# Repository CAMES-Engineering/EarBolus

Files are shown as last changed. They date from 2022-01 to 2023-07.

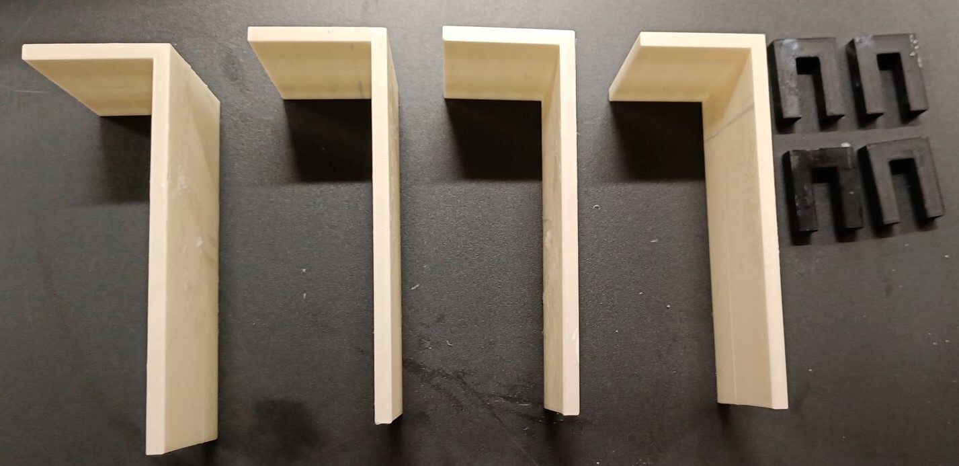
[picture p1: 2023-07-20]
ideas/mouldbox.jpg

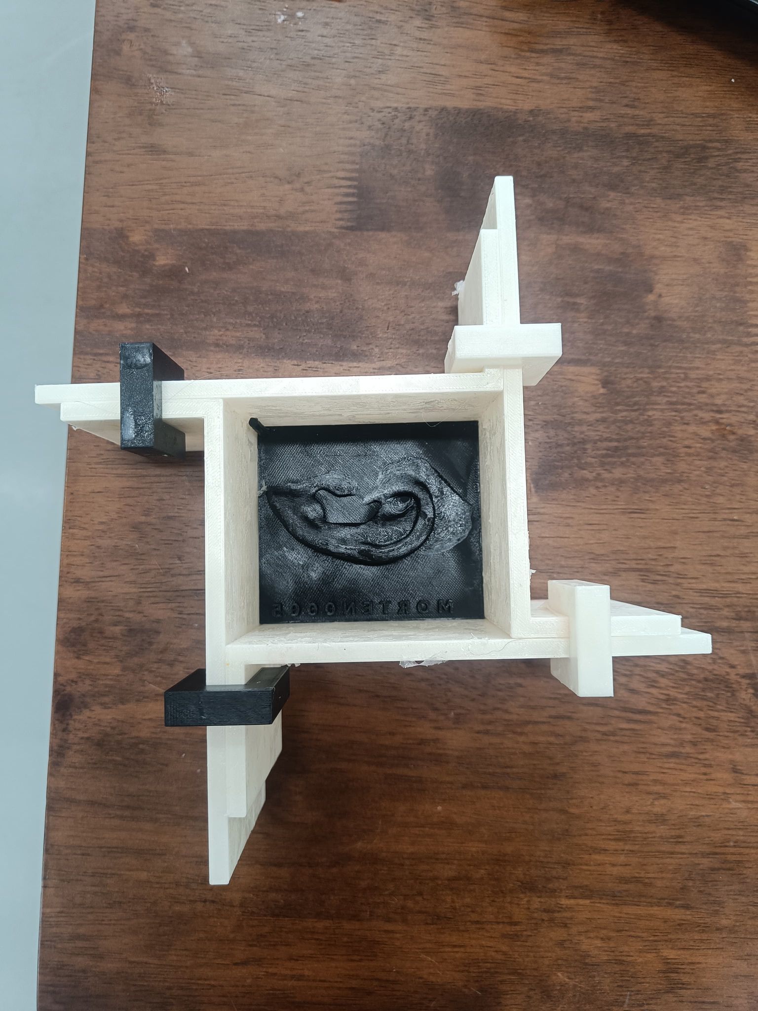
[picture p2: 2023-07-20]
ideas/311189066_1258065511643426_81849883111388684_n (1) (1).jpg

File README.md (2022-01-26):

# EarBolus

# Projekt trin

Aftalte trin med Kiki  
 + Text i model

Lav trin i denne fil.

Overvej om der skal laves ændringerne i ørefilerne for at de kan printes.

Meshmixer til smoothing af øre

# Færdige trin

<del>Kiki status</del>

---

## Requirements

Krav til Bolus i silikone
10mm over højeste sted på øret

### Spørgsmål
Hvad er præcisionskravet ?

### First attempts

1 - Kasse (Generisk)  
2 - Øre der passer i
    Skæres flad i bunden så den kan lægge i formen
3 - Målestok til at hælde silikone i

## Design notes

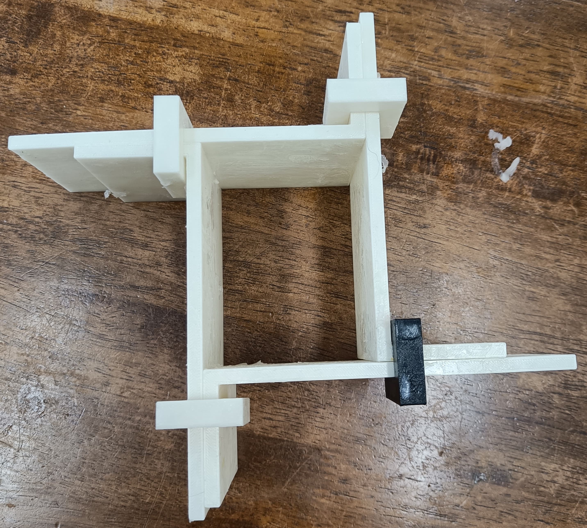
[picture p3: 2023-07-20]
ideas/mouldboxcollected.jpg

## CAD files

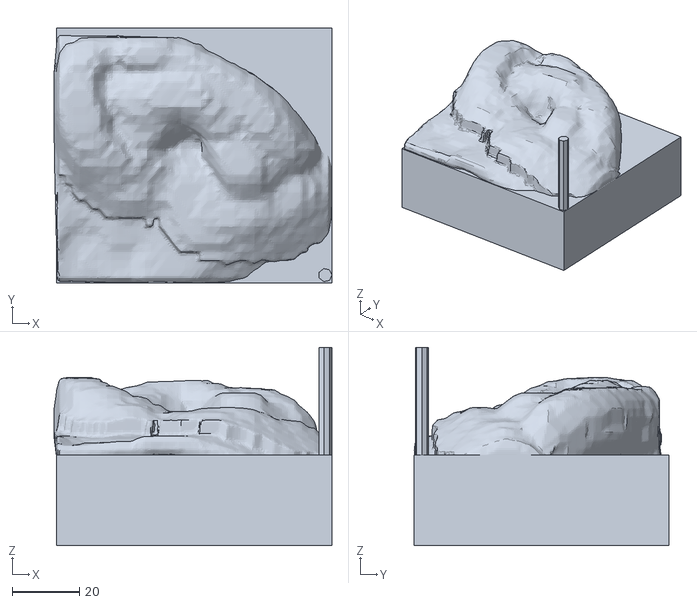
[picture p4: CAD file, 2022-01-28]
ideas/earcylinder.stl
82.7 x 76.0 x 59.0

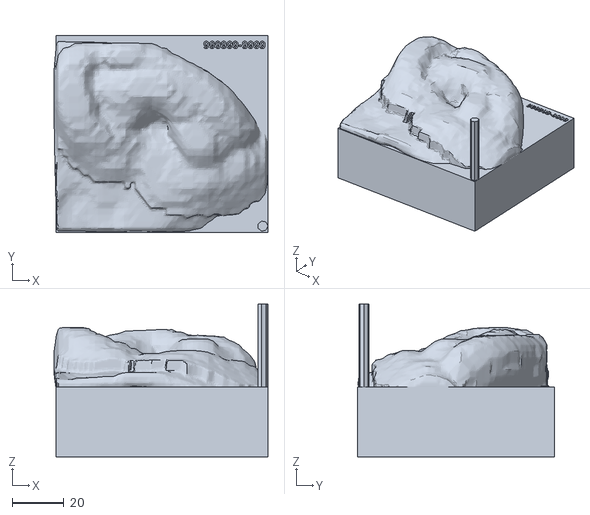
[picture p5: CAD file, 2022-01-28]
ideas/w_CPRearcylinder.stl
82.7 x 76.0 x 59.0

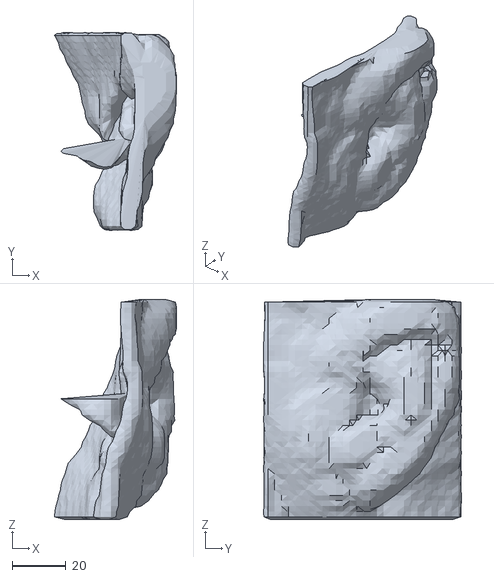
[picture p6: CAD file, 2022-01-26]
ideas/Bolus.stl
45.5 x 73.9 x 82.0

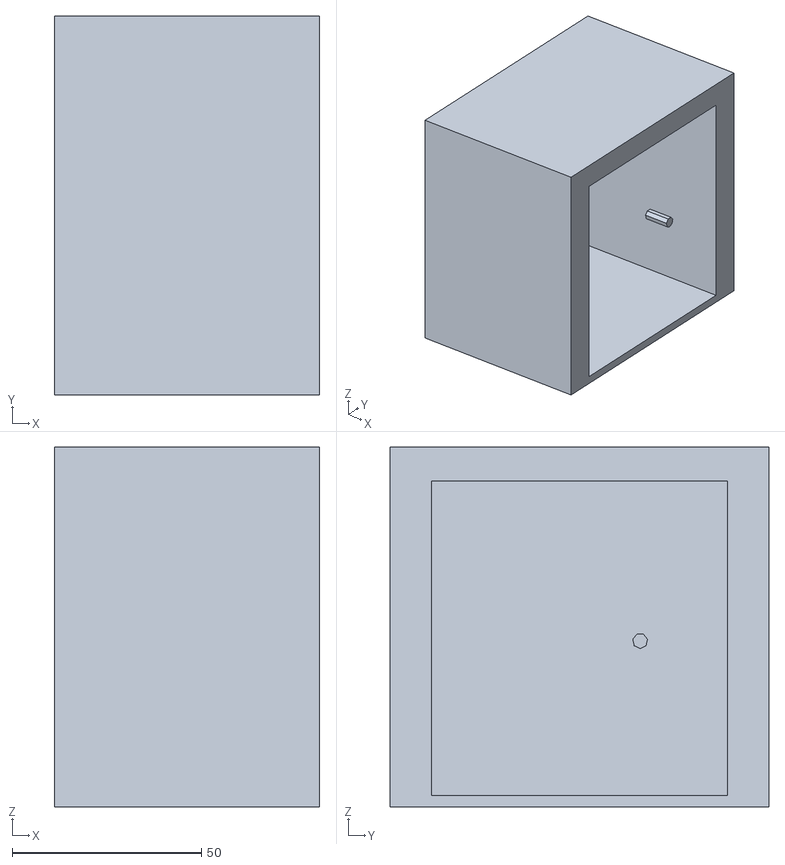
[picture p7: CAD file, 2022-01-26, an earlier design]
ideas/old/kassebolusmeassurerigtige.stl
70.0 x 100.0 x 95.0

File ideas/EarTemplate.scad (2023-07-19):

include <includingScriptEarBolus.scad>
// IMPORTANT make sure the EarTemplate.scad and includingScriptEarBolus.scad are located in the same folder

// Insert the file path here. You can drag and drop it, or copy the file path. If you drag and drop remember to remove <import()>
filename= "";//Insert file path here

// Insert the CPR number of the patient and the identification number here separate each number with space
CPRnumber="0 0 0 0 0 0 0 0 0 0 0 0";

//Change the bolus thickness the physician ordered the bolus in milimeters.
bolus_thick = 0; //mm

//If needed rotate the ear. The longer side of the ear should be beside the CPR-number
rotate_ear_x = 0; //rotate on x axis
rotate_ear_y = 0;   //rotate on y axis
rotate_ear_z = 0;  //rotate on z axis

// Change the placement of the base square so it fits under the ear. There must be NO HOLES between the ear and square
x_move_box = 0;   //move on x axis
y_move_box = 0;   //move on y axis
z_move_box = 0;    //move on z axis

// If needed change the size of the square. The ear must NOT be over the edges.
x_box = 90;
y_box = 90;
z_box = 10;

//Change placement of small (GREY) cylinder and place it on the highest point of the ear the ensure the minimum thickness.
x_move_small_cylinder= 0;    //changing x-axis
y_move_small_cylinder= 0;      //changing y-axis
z_move_small_cylinder= 0;   //changing z-axis

//Do not change the parameters below
union(){
rotate([rotate_ear_x,rotate_ear_y,rotate_ear_z])
    import(filename);
translate([x_move_box,y_move_box,z_move_box])earbox(x_box,y_box,z_box,CPRnumber,z_move_small_cylinder,bolus_thick,z_move_box);
};
%translate([x_move_small_cylinder,y_move_small_cylinder,z_move_small_cylinder])cylinder(bolus_thick,2,2);

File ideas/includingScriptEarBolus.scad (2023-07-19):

module earbox(x_box,y_box,z_box,CPRnumber,z_move_small_cylinder, bolus_thick,z_move_box){

//Change the placement of the CPR-number. Make sure it is opposite the cylinder on the extra space made on the box. If some of the ear disappears then the CPR-number needs to be placed further away from the ear. You might have to enlarge the box more.
x_move_CPRnr = 4;
y_move_CPRnr = y_box-5;
z_move_CPRnr = z_box+3;


// Change the placement of the blue cylinder. It should be placed as far in the corner as possible.
x_move_blue_cylinder= x_box-3;
y_move_blue_cylinder= 3;
z_move_blue_cylinder= z_box;


module cubeEar(){
    cube([x_box,y_box,z_box]);
    color("red")
    
        translate([x_move_CPRnr,y_move_CPRnr,z_move_CPRnr])
        rotate([-180,0,0])
        linear_extrude(4)
        text(CPRnumber,font="DejaVu Sans:style=Bold", size=5);
    translate([x_move_blue_cylinder,y_move_blue_cylinder,z_move_blue_cylinder])color("blue")cylinder((z_move_small_cylinder+bolus_thick)-z_box-z_move_box,2,2);
}
cubeEar();

}


    

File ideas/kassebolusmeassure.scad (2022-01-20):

difference(){
translate([-20,-63,-4])cube([70,100,95]);
    translate([-12,-52,-1])cube([70,78,83]);
    };
translate([-50,200,-20])import("C:/Users/Sanne/Downloads/Bolus.stl");
    rotate([0,90,0])translate([-39.8,3,35.7])cylinder(10,2,2);

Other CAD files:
ideas/kassebolusmeassure1.scad
ideas/klips til kasse.scad
ideas/magnusoeretest.scad
ideas/old/defaultscriptearbolus.scad
ideas/old/earcprcylinder.scad
ideas/old/earcylinder.scad
ideas/old/kassebolusmeassure1.scad
ideas/old/kassebolusmeassurerigtige.scad
ideas/old/magnusoeretest.scad
ideas/old/tekst.scad
ideas/old/w_cprearcylinder.scad
ideas/tekst.scad
ideas/w_cprearcylinder.scad

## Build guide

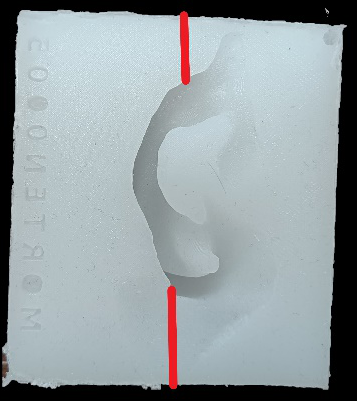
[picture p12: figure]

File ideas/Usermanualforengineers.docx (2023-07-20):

# Usermanual for engineers

How to prepare 3D scan and generate mould for ear bolus

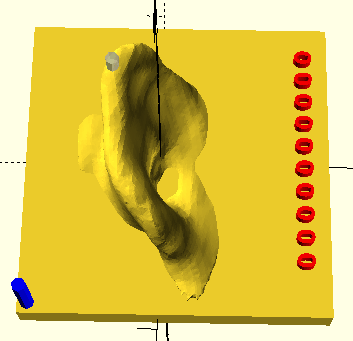
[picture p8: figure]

About this manual
This user manual is for engineers making a mould for an ear bolus. This manual will explain how to prepare the raw 3D scan, make the mould and what software to use for it.

It is recommended to follow the manual to get the best results.

# Cropping the 3D scan

1. Download the 3D scanning of the patient on the R-drive on your Region H computer.
2. Import the OBJ.file into meshmixer
3. Use the inspector tool in analysis. Use the smooth fill mode. Remember to press “autorepair all”.
4. Crop the model. Crop out the ear but leave some on the sides. The cropping can be done in two ways.
  a. Use the select tool and select the ear and some surroundings (orange is selected). Then press “i” to invert the selection and then press “x” to delete.
  b. Use the select tool to draw a line across the model where you want to cut it. You must start the line outside the model. After “i” can be used to invert and “x” to delete.
5. Use the inspector tool again. Use the smooth fill mode. Remember to press “autorepair all”
6. Use the “make solid” tool in edit. You want to use the “accurate” solid type. Press update and accept.
7. If you need to cut more off the model just follow the steps from step 3 again.
8. Go to edit and use “align”. Source should be “basepoint”, destination “world origin/Y-up” and transformation “translate and rotate”.
9. When the 3D model looks like this you need to save it as an STL file.

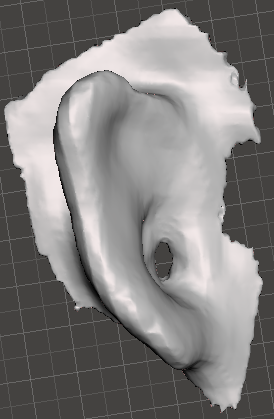
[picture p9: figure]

!! Important to have it as an STL file and not overwr ite the original OBJ file !!

# Making the bolus mould

1. Open the EarTemplate.scad in OpenSCAD.
2. Import the solid 3D model into OpenSCAD. If you drag and drop the STL file remember to remove <import()>.
3. Write the patient’s CPR number and separate each number with space without special signs.
4. Follow the steps in the script until the mould looks like this:

It is important the ear is rotated this way and that there is NO HOLES between the ear and the base plate.

5. Placing the small (grey) cylinder is important it is placed on the highest/tallest point of the ear. If the small (grey) cylinder is not visible, try changing the z-axis. It should look like the picture underneath.

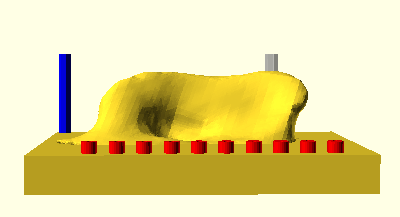
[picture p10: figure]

6. Save the finished mould as an STL file

The mould is now ready for printing.

# Prepare model for printing

1. Print the mould using a Prusa i3 MK3S printer
2. Use PLA filament on the printer
3. Import the STL file into PrusaSlicer
4. Make sure the settings are as the picture
5. Only 5 % infill.
6. Make sure to wash the printer bed before starting the print. Use warm water and soap

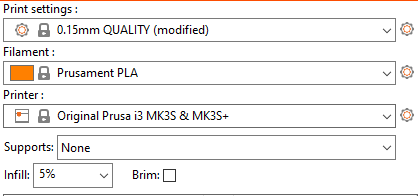
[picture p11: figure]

7. Export the gcode to a SD card
8. Put SD card into a Prusa i3 MK3S printer
9. Start the print.

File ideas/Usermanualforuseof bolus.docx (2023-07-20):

# User manual for use of bolus

# Introduction

Patient-Specific Bolus is a technique used in radiation therapy to provide customized radiation dose to a specific area of the body. It is a temporary material placed on the skin surface, which helps to shape the radiation beam and deliver a precise dose to the target area. This manual provides information about the use of patient-specific bolus in radiation therapy.

# Preparation

Before using patient-specific bolus, the following steps need to be taken:

1. The treatment plan for radiation therapy should be designed by the radiation oncologist.
2. The bolus should be selected based on the patient's anatomy and the radiation dose required for the target area.
3. The patient should be positioned on the treatment table as per the treatment plan.
4. The treatment area should be cleaned and dried.

If there are wounds or broken skin on the surface area, please cover this. Do not place bolus on wounds or broken skin.

# Application

The following steps should be followed for the application of patient-specific bolus:

1. The bolus should be placed on the skin surface covering the target area.
  a. If necessary, the bolus can be cut in the red areas marked on the picture for easier application. (See picture)
2. The bolus should be fastened with tape to the skin to prevent it from moving during treatment.

# During Treatment

During treatment, the following steps should be taken:

1. The radiation therapist should ensure that the bolus and the treatment area are in the correct position.
2. The radiation therapist should monitor the patient during treatment to ensure that the bolus and treatment area do not move.
3. The patient should remain still during treatment to ensure that the radiation beam is delivered accurately.

# Removal

After treatment, the following steps should be taken to remove the bolus:

1. The tape used to attach the bolus to the skin surface should be carefully removed.
2. The bolus should be gently removed from the skin surface.
3. The treatment area should be cleaned and dried.

If the patient has finished treatment the bolus is disposed of. If the patient needs more treatment save and store the bolus.

# Disposal

When the patient has finished all radiation treatments the bolus needs to be disposed of. Cut off the ID on the bolus and cut it into smaller pieces using scissors. Dispose of it in the trash.

# Conclusion

Patient-Specific Bolus is an important technique used in radiation therapy to provide a precise dose of radiation to the target area. By following the steps outlined in this manual, radiation therapists can ensure that patient-specific bolus is used safely and effectively.
